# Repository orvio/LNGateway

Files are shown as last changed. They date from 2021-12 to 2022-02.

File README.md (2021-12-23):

# LNGateway
LNGateway is an opto isolated DIY interface between Loconet and a serial interface based on an Arduino micro.

The main purpose is to provide a gateway for throttle messages between wifi trottles connected to JMRI and a DCC command station.
It understands enough Loconet to block certain message types in order to cut down on traffic on either side of the bridge.

Additional documentation and instructions are available under [https://orvio.github.io/LNGateway](https://orvio.github.io/LNGateway)

It can use a i2c OLED display to show the messages passed through it.

It works in JMRI with the LocoBuffer interface driver.

The TX_PIN must be set to 5 if the circuit is built as documented in the KiCad files. It is compatible with the LocoLinx example sketch from the LocoNet library as long as the TX_PIN is set correctly.

The board design matches the mounting hole spacing of a Raspberry Pi.

Full board:

Full board

Board without display and Arduino:

Board without display and Arduino

Detail view:

Detail view

Modification to have the V2 circuit on the V1 board:

Modification to have the V2 circuit on the V1 board

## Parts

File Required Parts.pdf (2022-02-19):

LocoBridge BOM

Part Name | Notes | Amount | Price (€) | Total (€)
Arduino Micro | with headers | 1 | 16,90 € | 16,90 €
0.96” SSD1306 OLED | available from JOY-IT and many others | 1 | 7,30 € | 7,30 €
Electrolytic Cap 22uF | 50V; 2mm pitch;radial | 1 | 0,09 € | 0,09 €
| 16V;2.5mm(0.1”) pitch;radial | 1 | 0,11 € | 0,11 €
Electrolytic Cap 100nF | 16V; 1.5mm pitch;radial | 1 | 0,02 € | 0,02 €
B40R Bridge Rectifier | | 1 | 0,25 € | 0,25 €
1N5817 Diode | | 1 | 0,05 € | 0,05 €
Pinsocket 1x17 | 2.5mm(0.1”) pitch | 2 | 0,60 € | 1,20 €
RJ12 Socket | | 1 | 0,40 € | 0,40 €
Pinsocket 1x4 | 2.5mm(0.1”) pitch | 1 | 0,17 € | 0,17 €
Pinheader 1x2 | 2.5mm(0.1”) pitch | 1 | 0,05 € | 0,05 €
Inductor 300uH | 5mm(0.2”) pitch;radial | 1 | 0,31 € | 0,31 €
LED 3mm | 2.5mm(0.1”) pitch | 6 | 0,12 € | 0,72 €
4n35 opto couple | DIP-6 package | 2 | 0,26 € | 0,52 €
2N3904 Transistor | TO-92 package | 2 | 0,05 € | 0,10 €
2N3906 Transistor | TO-92 package | 1 | 0,05 € | 0,05 €
47kOhm Resistor | Metal 1%; 0207 | 1 | 0,08 € | 0,08 €
4.7kOhm Resistor | Metal 1%; 0207 | 1 | 0,08 € | 0,08 €
150kOhm Resistor | Metal 1%; 0207 | 1 | 0,08 € | 0,08 €
22kOhm Resistor | Metal 1%; 0207 | 2 | 0,08 € | 0,16 €
10kOhm Resistor | Metal 1%; 0207 | 3 | 0,08 € | 0,24 €
1kOhm Resistor | Metal 1%; 0207 | 2 | 0,08 € | 0,16 €
2.2kOhm Resistor | Metal 1%; 0207 | 1 | 0,08 € | 0,08 €
620Ohm Resistor | Metal 1%; 0207 | 1 | 0,08 € | 0,08 €
300Ohm Resistor | Metal 1%; 0207 | 8 | 0,08 € | 0,64 €
LM311 Comparator | DIP-8 | 1 | 0,34 € | 0,34 €
LM2574N-5 Sw. Reg. | DIP-8;5V Step-Down Switching Regulator | 1 | 1,60 € | 1,60 €
LNGateway PCB | Depends on manufacturer | 1 | 7,00 € | 7,00 €
| | | Total: | 38,78 €

Electrolytic Cap 220uF

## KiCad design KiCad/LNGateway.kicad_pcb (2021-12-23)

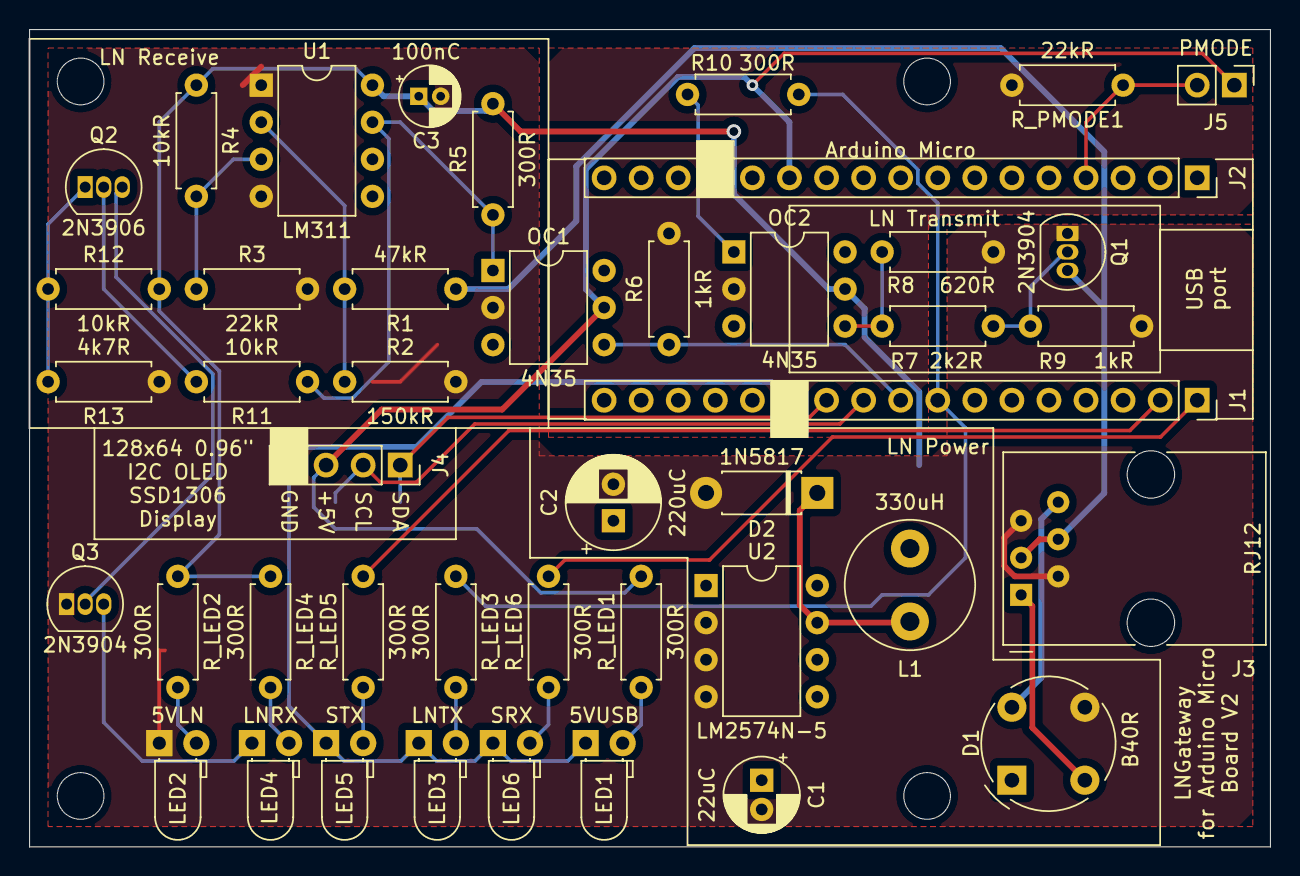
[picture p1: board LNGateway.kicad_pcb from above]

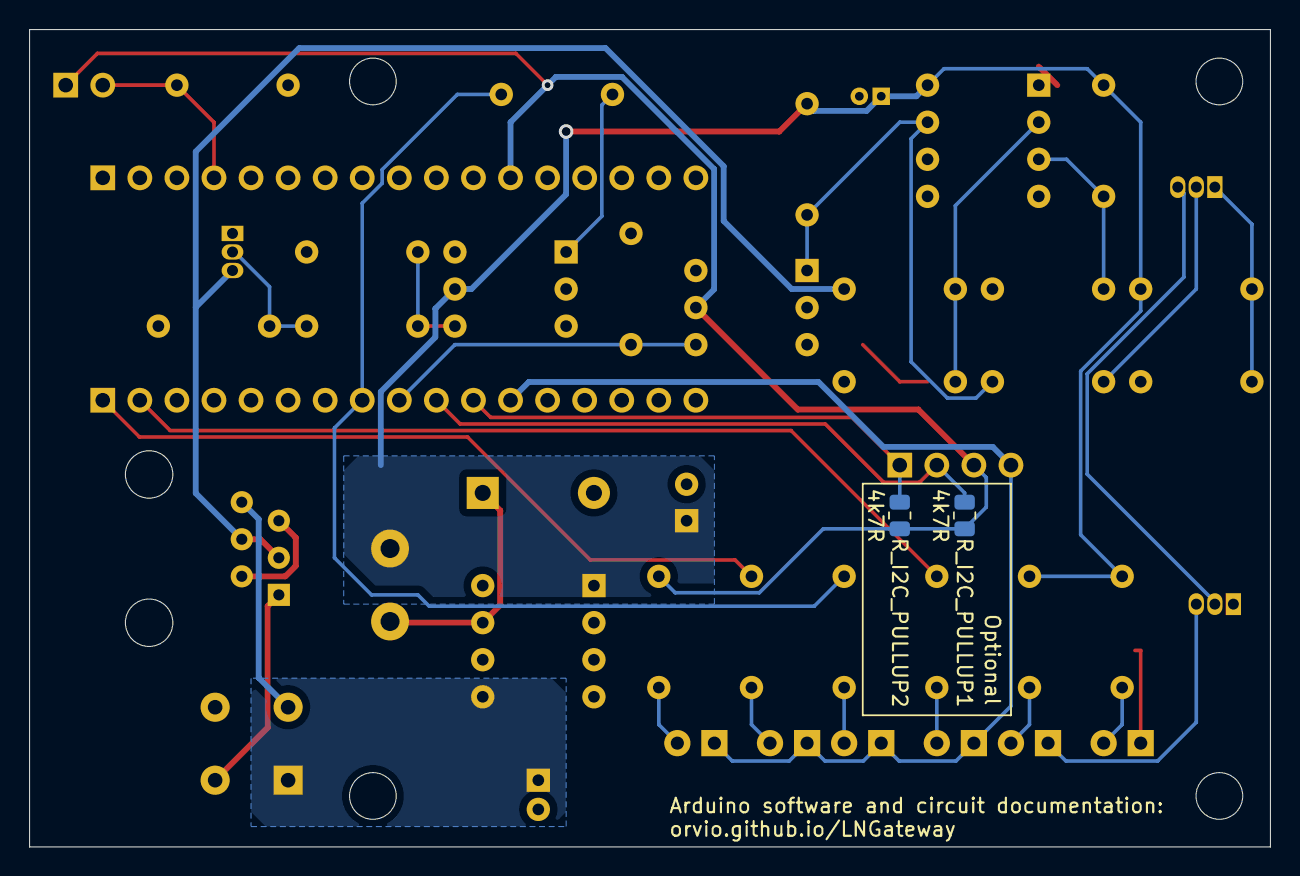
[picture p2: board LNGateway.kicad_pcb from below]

Board: 2 copper layers, 85.0 x 56.0 mm, 46 parts (2 on the bottom side), 32 nets.

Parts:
C1: 22uC; CP_Radial_D5.0mm_P2.00mm
C2: 220uC; CP_Radial_D6.3mm_P2.50mm
C3: 100nC; CP_Radial_D4.0mm_P1.50mm
D1: B40R; Diode_Bridge_Round_D9.0mm
D2: 1N5817; D_DO-41_SOD81_P7.62mm_Horizontal
J1, J2: Conn_01x17_Female; PinSocket_1x17_P2.54mm_Vertical
J3: RJ12; RJ12_Amphenol_54601
J4: Conn_01x04_Female; PinSocket_1x04_P2.54mm_Vertical
J5: Conn_01x02_Male; PinHeader_1x02_P2.54mm_Vertical
L1: 330uH; L_Radial_D8.7mm_P5.00mm_Fastron_07HCP
LED1, LED2, LED3, LED4, LED5, LED6: LED; LED_D3.0mm_Horizontal_O1.27mm_Z2.0mm
OC1, OC2: 4N35; DIP-6_W7.62mm
Q1, Q3: 2N3904; TO-92_Inline
Q2: 2N3906; TO-92_Inline
R1: 47kR; R_Axial_DIN0207_L6.3mm_D2.5mm_P7.62mm_Horizontal
R2: 150kR; R_Axial_DIN0207_L6.3mm_D2.5mm_P7.62mm_Horizontal
R3: 22kR; R_Axial_DIN0207_L6.3mm_D2.5mm_P7.62mm_Horizontal
R4, R11, R12: 10kR; R_Axial_DIN0207_L6.3mm_D2.5mm_P7.62mm_Horizontal
R5, R10: 300R; R_Axial_DIN0207_L6.3mm_D2.5mm_P7.62mm_Horizontal
R6, R9: 1kR; R_Axial_DIN0207_L6.3mm_D2.5mm_P7.62mm_Horizontal
R7: 2k2R; R_Axial_DIN0207_L6.3mm_D2.5mm_P7.62mm_Horizontal
R8: 620R; R_Axial_DIN0207_L6.3mm_D2.5mm_P7.62mm_Horizontal
R13: 4k7R; R_Axial_DIN0207_L6.3mm_D2.5mm_P7.62mm_Horizontal
R_I2C_PULLUP1, R_I2C_PULLUP2: 4k7R; R_0805_2012Metric
R_LED1, R_LED2, R_LED3, R_LED4, R_LED5, R_LED6: 300R; R_Axial_DIN0207_L6.3mm_D2.5mm_P7.62mm_Horizontal
R_PMODE1: 22kR; R_Axial_DIN0207_L6.3mm_D2.5mm_P7.62mm_Horizontal
U1: LM311; DIP-8_W7.62mm
U2: LM2574N-5; DIP-8_W7.62mm

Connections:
+5V: J2.12, J4.3, J5.1, OC1.5, R_I2C_PULLUP1.2, R_I2C_PULLUP2.2, R_LED1.2
/1V5: Q2.1, R12.1, R13.2
/LN: J3.3, J3.4, Q1.3, R1.1
/LN_5V_RAW: D2.1, L1.2, U2.7
/LN_RX: OC1.1, R5.1, R11.1, U1.7
/LN_RX_Arduino: J1.9, OC1.4, R6.1
/LN_TX: OC2.4, R7.1, R8.1
/LN_TX_1V5: Q1.2, R7.2, R9.1
/LN_TX_Arduino: J1.8, R10.1, R_LED3.1
/LN_VIN: C1.1, D1.1, U2.5
/PMODE: J2.4, J5.2, R_PMODE1.1
/RAIl_SYNC_1: D1.4, J3.6
/RAIl_SYNC_2: D1.2, J3.1
/REF_3V44: R3.1, R4.2, U1.3
/SCL: J1.10, J4.2, R_I2C_PULLUP1.1
/SDA: J1.11, J4.1, R_I2C_PULLUP2.1
/SERIAL_RX: J1.1, R_LED6.2
/SERIAL_TX: J1.2, R_LED5.2
/VLN_IN_9NOM_3V8MIN_18VMAX: R1.2, R2.1, U1.2
GND1: C1.2, C2.2, C3.2, D1.3, D2.2, J3.2, J3.5, LED2.1, OC1.2, Q1.1, Q3.1, R2.2, R3.2, R8.2, R9.2, R13.1, U1.1, U1.4, U2.2, U2.3, U2.4
GND2: J1.12, J2.14, J4.4, LED1.1, LED3.1, LED5.1, LED6.1, OC2.2, R6.2, R_PMODE1.2
unnamed: LED1.2, R_LED1.1
unnamed: LED2.2, R_LED2.2
unnamed: LED3.2, R_LED3.2
unnamed: LED4.1, Q3.3
unnamed: LED4.2, R_LED4.2
unnamed: LED5.2, R_LED5.1
unnamed: LED6.2, R_LED6.1
unnamed: OC2.1, R10.2
unnamed: Q2.2, R11.2
unnamed: Q2.3, Q3.2
VDD: C2.1, C3.1, L1.1, OC2.5, R4.1, R5.2, R12.2, R_LED2.1, R_LED4.1, U1.8, U2.1

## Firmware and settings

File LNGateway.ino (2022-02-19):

/*
    This file is part of the LNGateway project.
    
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
    You should have received a copy of the GNU General Public License
    along with this program.  If not, see <https://www.gnu.org/licenses/>.
*/

// This sketch requires the LocoNet ad Adafruit SSD1306 libraries
#include <SPI.h>
#include <Adafruit_GFX.h>
#include <Adafruit_SSD1306.h>
#include <LocoNet.h>

//set to 1 to hide blocked messages
#define HIDE_BLOCKED_MESSAGES 1

//block switch requests from the serial interface
#define BLOCK_OPC_SW_REQ 1

#define SCREEN_WIDTH 128 // OLED display width, in pixels
#define SCREEN_HEIGHT 64 // OLED display height, in pixels

// Declaration for an SSD1306 display connected to I2C (SDA, SCL pins)
#define OLED_RESET     -1 // Reset pin # (or -1 if sharing Arduino reset pin)
#define SCREEN_ADDRESS 0x3C ///< See datasheet for Address; alternatively use the Wire.>i2x_scanner example sketch from the Arduino IDE
Adafruit_SSD1306 display(SCREEN_WIDTH, SCREEN_HEIGHT, &Wire, OLED_RESET);

//LN TX pin
#define TX_PIN   5
//#define LN_TX_ECHO 0
static LnBuf lnTXBuffer;
static lnMsg *lnPacket;



//text size 1 gives 8 display lines; size 2 reduces that to 4
#define DISPLAY_LINES 8
#define TEXT_SIZE 1

//pins for external serial RX/TX LED pins
#define RX_LED_PIN 12
#define TX_LED_PIN 11

//programming pin to tell the arduino to close the serial port
#define PROGRAMMING_PIN A0

#define BAUD_RATE 57600
bool serialOpen = false;

bool displayAvailable = false;

enum DisplayStates { UpdateDisplayBuffer, SendDisplayBuffer};
DisplayStates displayState = UpdateDisplayBuffer;

enum MessageStates { SerialPass, SerialBlock, SerialError, LocoPass, LocoBlock, LocoError};

String displayStrings[DISPLAY_LINES];
short displayLineIndex = 0;

unsigned long lastDisplayUpdateMs = 0;
unsigned long lastSerialReceiveMs = 0;

#define SERIAL_BYTES_LIMIT 16
byte serialBytes[SERIAL_BYTES_LIMIT];
byte serialByteIndex = 0;

void setup() {
  // put your setup code here, to run once:

  delay(500);

  pinMode(LED_BUILTIN, OUTPUT);

 //Check if the display is present on the i2c bus
  Wire.begin();
  Wire.beginTransmission(SCREEN_ADDRESS);
  if (!Wire.endTransmission()) { //someone responded under the display address
    // SSD1306_SWITCHCAPVCC = generate display voltage from 3.3V internally
    if (display.begin(SSD1306_SWITCHCAPVCC, SCREEN_ADDRESS)) {
      displayAvailable = true;
    }
  }
  else {
    displayAvailable = false;
  }


  //using the built in led to indicate display detection
  if (displayAvailable) {
    display.clearDisplay();
    display.display();
    digitalWrite(LED_BUILTIN, LOW);
  }
  else {
    digitalWrite(LED_BUILTIN, HIGH);
  }

  //leave the serial interface alone of the programming pin is HIGH
  if (!digitalRead(PROGRAMMING_PIN)) {
    Serial.begin(BAUD_RATE);
    Serial.flush();
    serialOpen = true;
  }
  else {
    serialOpen = false;
  }

  // First initialize the LocoNet interface, specifying the TX Pin
  LocoNet.init(TX_PIN);

  // Initialize a LocoNet packet buffer to buffer bytes from the PC
  initLnBuf(&lnTXBuffer);

  pinMode(RX_LED_PIN, OUTPUT);
  digitalWrite(RX_LED_PIN, HIGH);
  pinMode(TX_LED_PIN, OUTPUT);
  digitalWrite(TX_LED_PIN, HIGH);
  displayStrings[displayLineIndex] = "LNGateway";
  if (!serialOpen) {
    incrementDisplayLine();
    displayStrings[displayLineIndex] = "Serial closed";
  }
}

//locobuffer.com
void loop() {
  // put your main code here, to run repeatedly:
  if (serialOpen && Serial) {
    digitalWrite(RX_LED_PIN, LOW);
    digitalWrite(TX_LED_PIN, LOW);
  }
  else {
    digitalWrite(RX_LED_PIN, HIGH);
    digitalWrite(TX_LED_PIN, HIGH);
  }

  if (digitalRead(PROGRAMMING_PIN)) {
    if (serialOpen) {
      Serial.end();
      serialOpen = false;
      incrementDisplayLine();
      displayStrings[displayLineIndex] = "Serial closed";
    }
  }
  else if (!serialOpen) {
    Serial.begin(BAUD_RATE);
    Serial.flush();
    serialOpen = true;
    incrementDisplayLine();
    displayStrings[displayLineIndex] = "Serial opened";
  }

  processSerialData();
  processLocoData();

  /*
    Updating the dispay over i2c takes about 37ms.
    Updating the display buffer to show the messages takes about the same time, so the process is split
    in two phases 125ms apart so the display will update every 250ms.
  */
  if ( displayAvailable && (millis() > (lastDisplayUpdateMs + 100))) {
    switch (displayState) {
      case UpdateDisplayBuffer:
        display.clearDisplay();

        display.setTextSize(TEXT_SIZE);
        display.setTextColor(SSD1306_WHITE); // Draw white text
        display.setCursor(0, 0);     // Start at top-left corner
        display.cp437(true);         // Use full 256 char 'Code Page 437' font

        for (int i = 0; i <= displayLineIndex; i++) {
          display.println(displayStrings[i]);
        }
        displayState = SendDisplayBuffer;
        break;
      case SendDisplayBuffer:
        display.display();
        displayState = UpdateDisplayBuffer;
        break;
    } //switch displayState
    lastDisplayUpdateMs = millis();
  }

}

void processSerialData(void) {
  if (serialOpen && Serial.available()) {
    //read the incoming byte:

    digitalWrite(RX_LED_PIN, HIGH); //indicate that we received data from the PC
    lastSerialReceiveMs = millis();
    serialBytes[serialByteIndex] = Serial.read();
    serialByteIndex++;

    byte messageLength = getMessageLength(serialBytes, serialByteIndex);
    if (messageLength &&
        serialByteIndex >= messageLength) { //message complete
      switch (serialBytes[0]) {
        //blocked messages
        #if BLOCK_OPC_SW_REQ
        case OPC_SW_REQ: //Switch Request
          if ( testCheckSum(serialBytes, serialByteIndex) ) {
            updateDisplayStrings(SerialBlock, serialBytes, serialByteIndex);
          }
          else {
            updateDisplayStrings(SerialError, serialBytes, serialByteIndex);
          }

          break;
        #endif
        default: //pass on everything we did not want to block
          copyMessageToTXBuffer(serialBytes, serialByteIndex);
      } //switch opcode

      serialByteIndex = 0; //reset serial buffer
    }//message complete
    else if (serialByteIndex >= SERIAL_BYTES_LIMIT) { //this should never happen
      updateDisplayStrings(SerialError, serialBytes, serialByteIndex);
      serialByteIndex = 0; //reset serial buffer
    }
  } //serial byte available
  else if ((millis() > lastSerialReceiveMs + 500)
           && serialByteIndex) { //clear buffer if we get incomplete stuff to reset communication
    updateDisplayStrings(SerialError, serialBytes, serialByteIndex);
    serialByteIndex = 0;
  }

  //send outgoing LN packet
  lnPacket = recvLnMsg(&lnTXBuffer);
  if (lnPacket) {
    // Send the received packet from the PC to the LocoNet
    LocoNet.send( lnPacket );
  }

}

void processLocoData(void) {
  // Check for any received LocoNet packets
  lnPacket = LocoNet.receive() ;
  if (lnPacket) {
    // Get the length of the received packet
    byte Length = getLnMsgSize( lnPacket ) ;
    bool passMessage = true;

    if (testCheckSum(lnPacket->data, Length)) {
      //Blocking throttle messages from the LN side seems to confuse JMRI
      //So let's not do that anymore
      /*switch (lnPacket->data[0]) {
        //blocked messages from the LN side
        case OPC_RQ_SL_DATA: //Slot data request
        case OPC_LOCO_ADR: //Loco address request
        case OPC_LOCO_SPD: //Loco speed
        case OPC_LOCO_DIRF: //Loco Direction and F0-F4
        case OPC_LOCO_SND: //Loco sound functions
          passMessage = false;
          break;
        default:
          break;
      }*/

      if (passMessage) {
        // Send the received packet out byte by byte to the PC
        if (serialOpen) {
          digitalWrite(TX_LED_PIN, HIGH); //indicate that we are sending data to the PC
          for ( int i = 0; i < Length; i++ ) {
            Serial.write(lnPacket->data[i]);
          }
        }
        updateDisplayStrings(LocoPass, lnPacket->data, Length);
      }
      else {
        updateDisplayStrings(LocoBlock, lnPacket->data, Length);
      }
    }
    else {
      updateDisplayStrings(LocoError, lnPacket->data, Length);
    }
  }
}


byte getMessageLength(const byte bytes[], byte byteCount) {
  byte messageLength = 0;
  if ( byteCount ) {
    switch (bytes[0] & 0xE0) {
      case 0xE0: //N byte message
        if (byteCount >= 2 ) { //length byte available
          messageLength = bytes[1];
        }
        break;
      case 0xC0: //6 byte message
        messageLength = 6;
        break;
      case 0xA0: //4 byte message
        messageLength = 4;
        break;
      case 0x80: //2 byte message
        messageLength = 2;
        break;
    }
  }
  return messageLength;
}

void copyMessageToTXBuffer(const byte bytes[], byte byteCount) {
  if ( testCheckSum(bytes, byteCount) ) {
    updateDisplayStrings(SerialPass, bytes, byteCount);
    for (int i = 0; i < serialByteIndex; i++ ) {
      addByteLnBuf(&lnTXBuffer, bytes[i] & 0xFF);
    }
  }
  else {
    updateDisplayStrings(SerialError, bytes, byteCount);
  }
}

bool testCheckSum(const byte bytes[], byte byteCount) {
  byte check = 0;

  for (int i = 0; i < byteCount; i++) {
    check ^= bytes[i];
  }

  return check == 0xFF;
}

void updateDisplayStrings(MessageStates messageState, const byte bytes[], byte byteCount) {
  if ((messageState == SerialBlock || messageState == LocoBlock)
      && HIDE_BLOCKED_MESSAGES) {
    return;
  }

  incrementDisplayLine();

  switch (messageState) {
    case SerialPass:
      displayStrings[displayLineIndex]  = " > ";
      break;
    case SerialBlock:
      displayStrings[displayLineIndex]  = " >|";
      break;
    case SerialError:
      displayStrings[displayLineIndex]  = " >X";
      break;
    case LocoPass:
      displayStrings[displayLineIndex]  = " < ";
      break;
    case LocoBlock:
      displayStrings[displayLineIndex]  = "|< ";
      break;
    case LocoError:
      displayStrings[displayLineIndex]  = "X< ";
      break;
    default:
      displayStrings[displayLineIndex]  = "";
  }

  displayStrings[displayLineIndex] += ':';

  for ( int i = 0; i < byteCount; i++) {
    if ( i && !(i % 8) ) { //go to next line after 8 bytes
      incrementDisplayLine();
      displayStrings[displayLineIndex]  = "    ";
    }

    String byteString = String(bytes[i], HEX);
    byteString.toUpperCase();
    if (byteString.length() < 2) {
      byteString = "0" + byteString;
    }
    displayStrings[displayLineIndex] += byteString;
  }
}

void incrementDisplayLine() {
  displayLineIndex++;
  if (displayLineIndex >= DISPLAY_LINES) {
    if (displayStrings[DISPLAY_LINES].length()) {
      for (int i = 1; i < DISPLAY_LINES; i++) {
        displayStrings[i - 1] = displayStrings[i];
      }
    }
    displayLineIndex = DISPLAY_LINES - 1;
  }
}

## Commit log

2021-11-14 Added V1 of circuit and board design. It does not work properly like this, so please don't actually use it.
    [LocoBridge.kicad_pcb, LocoBridge.sch]
2021-11-14 Updated circuit and board design to improve LN TX reliability
    [LocoBridge.kicad_pcb, LocoBridge.sch]
2021-11-14 Generated BOM files
2021-11-14 Added shopping list
    [Required Parts.ods]
2021-11-16 Renamed everything to LNGateway to avoid naming conflict with the existing LocoBridge BT interface
    [LNGateway.kicad_pcb, LNGateway.sch]
2021-11-16 Updated board silk screen for new name
    [LNGateway.kicad_pcb]
2021-12-20 Added title to schematic
    [LNGateway.sch]
2021-12-20 Added reference to github repo
    [LNGateway.kicad_pcb]
2022-02-13 Updated parts list
    [Required Parts.ods]
2022-02-19 No longer blocking throttle messages from LN bus
    Blocking throttle messages from LN seems to sometimes confuse JMRI
    [LNGateway.ino]

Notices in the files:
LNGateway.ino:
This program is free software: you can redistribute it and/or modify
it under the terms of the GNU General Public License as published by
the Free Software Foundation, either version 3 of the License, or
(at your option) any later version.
